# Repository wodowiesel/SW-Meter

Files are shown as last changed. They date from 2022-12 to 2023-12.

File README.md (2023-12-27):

# SW-Meter

Custom PCB design of an external S-&amp;Watt-Meter for radios. Useful for all radio enthusiasts and amateur HAM operators.

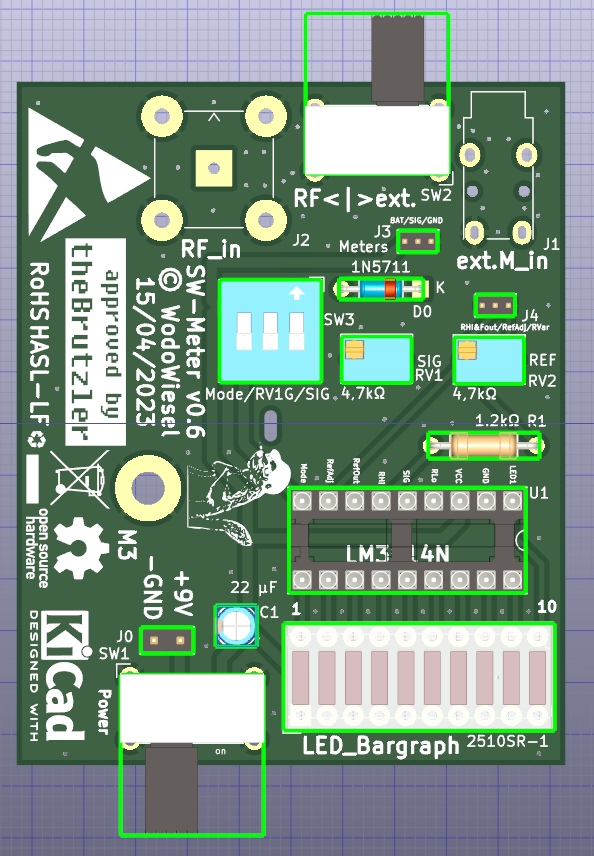
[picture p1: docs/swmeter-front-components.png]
PCB


## DISCLAIMERS

This is still "work-in-progress (WIP)" so I do NOT take any kind of warranty/responsibility for damages or data losses!

You can use this at your own risk without any guarantees and put device on non-conductive surface or enclosure!

If you like the new design you are free to share it!

Have fun and 73 :)

## HARDWARE

- 1x Custom THT PCB: (B) 66 x (L) 53 x (H) ~2 mm + ~15 mm parts height

  by WodoWiesel (wodowiesel@quantentunnel.de)

- 1x BNC male connector 50 Ohm Impedance

- 1x T-Adapter/cable for antenna/transceiver

- 1x 3.5 mm (or 2.5) audio jack female connector incl. a cable for hook up to your radio

- 1x +9 V Block Battery + 1x click connector

- 1x 330 Ohm Resistor – optional for LED

- 3x Variable Trimmer resistors 3-pins (1x1.2k & 2x4.7 kOhm)

- 1x Electrolytic Capacitor ~22 µF (pol.)

- 1x 3-pos. DIP-switch for additional signal/graph modes

- 1x On/Off-switch

- 1x 2-pos. 3-pin switch - for Input selection

- 2x DC-Volt-Meters 3-pins

- 1x Female Pin Headers/Socket - recommended for driver chip

- 1x LM3914 (linear), or 3915/16 (logarithmic dB) dot/bar display driver from Texas Instruments

  extra calculator (https://www.electro-tech-online.com/tools/LM3914V2.php)

- 1x 1N914 fast-switching Schottky Diode - to prevent backflow

- 10x LEDs (v0.5) or 1x Bar-Graph (v0.7)

- 1x M3 short flat head screw

- maybe metal case or 3D printed enclosure for isolation

- 1x Soldering iron & Screwdriver

- Solder + flux + IPA + brush + paper

- Multimeter/Oscilloscope for verification

## Credits

©️ 2022/23 WodoWiesel (https://github.com/wodowiesel/ & https://www.twitch.com/wodowiesel/)

The new design was checked by the electrical engineer theBrutzler

(https://github.com/theBrutzler/ & https://www.twitch.com/theBrutzler/)

The new optimized PCB was designed with free KiCAD software (https://www.kicad.org/)

The PCB should be produced at a manufacturer (like PCBWay) with the RoHS lead-free option for environmental protection

## LICENSE

This project is licensed under:

CERN Open Hardware License Version 2 - Weakly Reciprocal

Short identifier CERN-OHL-W-2.0

[LICENSE Source](https://spdx.org/licenses/CERN-OHL-W-2.0.html)

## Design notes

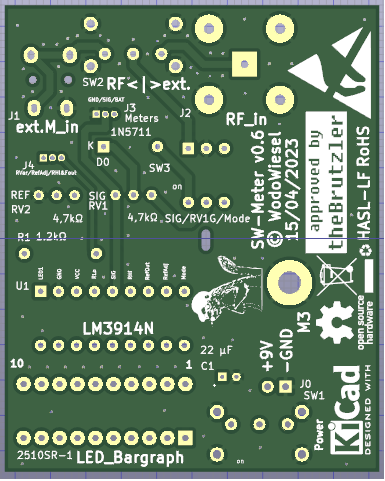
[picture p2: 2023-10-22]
docs/swmeter-back.png

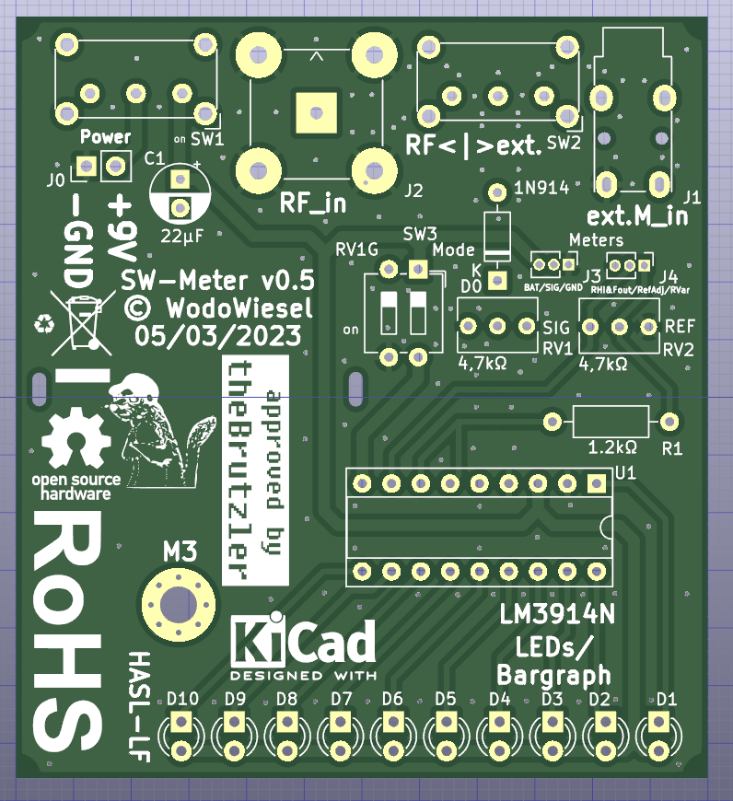
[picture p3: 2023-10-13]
docs/swmeter-front-led.png

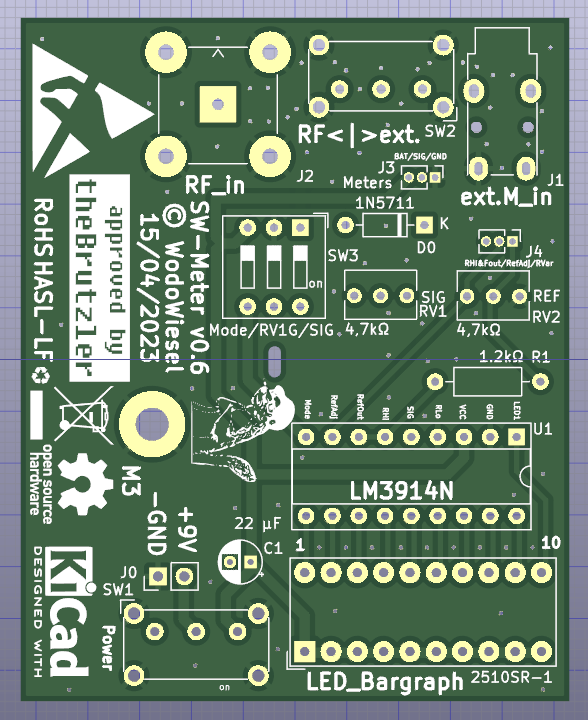
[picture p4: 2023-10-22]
docs/swmeter-front.png

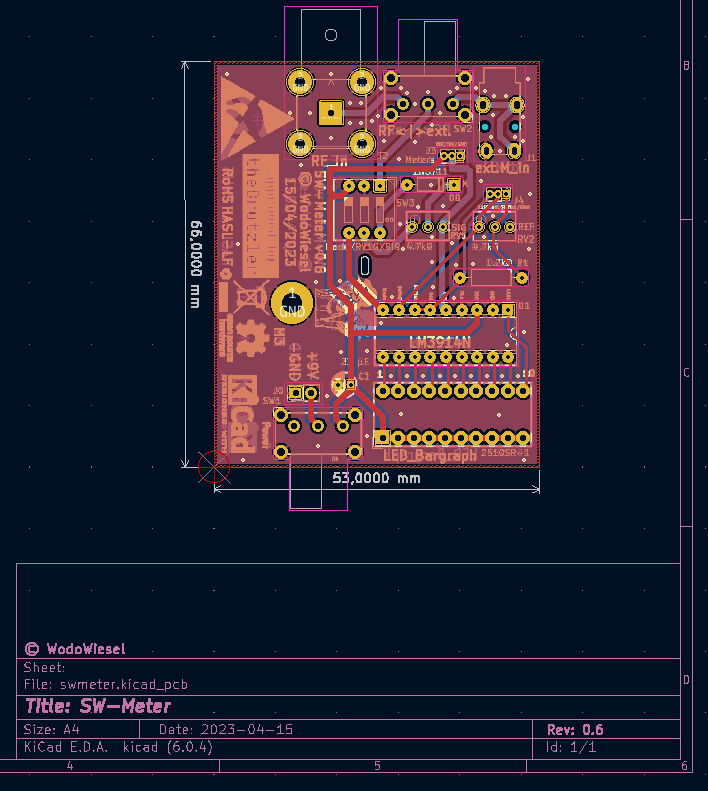
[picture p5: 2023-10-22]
docs/swmeter-v0.6-pcb.PNG

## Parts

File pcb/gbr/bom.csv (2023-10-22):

Designator | Footprint | Quantity | Value | LCSC Part #
BAR1 | HDSP-4836 | 1 | 2510SR-1
SW2 | SW_E-Switch_EG1224_SPDT_Angled | 1 | SW_SPDT
C1 | CP_Radial_D4.0mm_P2.00mm | 1 | 22 µF
J1 | Jack_3.5mm_Lumberg_1503_07_Horizontal | 1 | AudioPlug
RV1 | Potentiometer_Bourns_3266Y_Vertical | 1 | 4,7kΩ
SW1 | SW_E-Switch_EG1224_SPDT_Angled | 1 | SW_SPDT
J3 | PinHeader_1x03_P1.27mm_Vertical | 1 | Conn_01x03_Female
SW3 | SW_DIP_SPSTx03_Slide_9.78x9.8mm_W7.62mm_P2.54mm | 1 | SW_DIP_x03
D0 | D_DO-35_SOD27_P7.62mm_Horizontal | 1 | 1N5711
J4 | PinHeader_1x03_P1.27mm_Vertical | 1 | Conn_01x03_Female
R1 | R_Axial_DIN0207_L6.3mm_D2.5mm_P10.16mm_Horizontal | 1 | 1.2kΩ
U1 | DIP-18_W7.62mm_Socket | 1 | LM3914N
J2 | BNC_TEConnectivity_1478035_Horizontal | 1 | Conn_Coaxial
J0 | PinHeader_1x02_P2.54mm_Vertical | 1 | Conn_01x02_Female
RV2 | Potentiometer_Bourns_3266Y_Vertical | 1 | 4,7kΩ

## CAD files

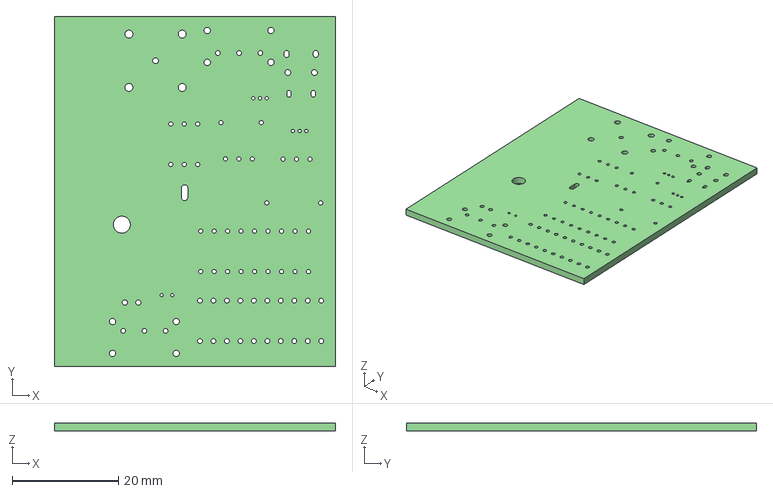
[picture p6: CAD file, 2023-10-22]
pcb/export/swmeter.step
53.0 x 66.0 x 1.60 mm

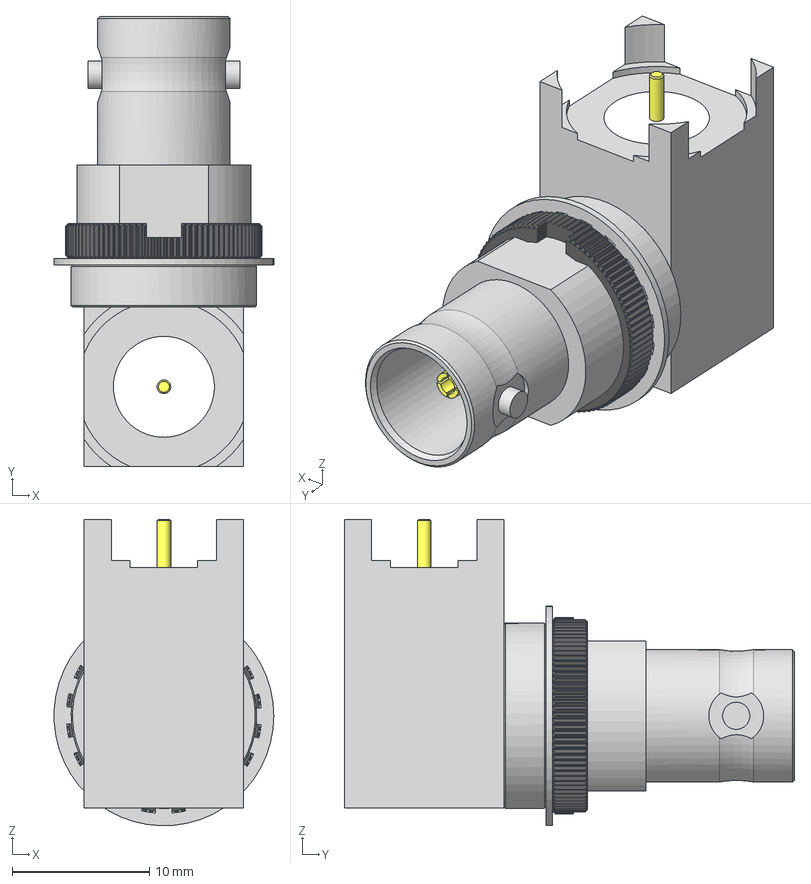
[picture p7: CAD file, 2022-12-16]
pcb/shapes3D/BNC7T-J-P-HN-RA-BH1.stp
16.0 x 32.8 x 22.3 mm
BNC7T-G-P-HN-RA-BH1_n
BNC7T-G-P-HN-RA-BH1_w
BNC7T-G-P-HN-RA-BH1_p
BNC7T-G-P-HN-RA-BH1_i
BNC7T-G-P-HN-RA-BH1_s

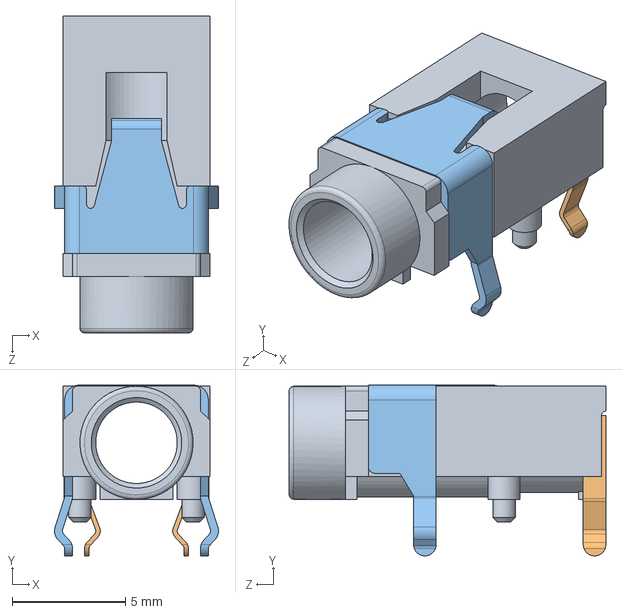
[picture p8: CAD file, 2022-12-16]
pcb/shapes3D/Lumberg_1503_07.stp
7.25 x 7.55 x 14.0 mm

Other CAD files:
pcb/swmeter.step

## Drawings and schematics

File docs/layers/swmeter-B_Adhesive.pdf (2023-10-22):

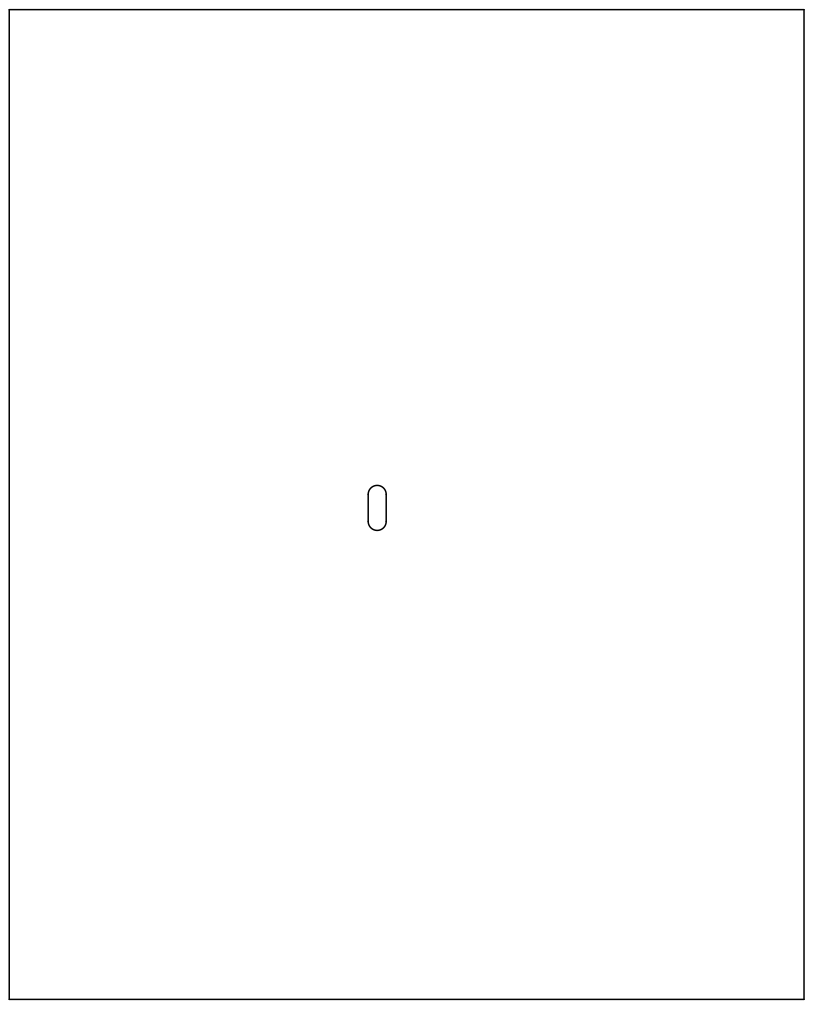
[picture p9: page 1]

File: swmeter.kicad_pcb Sheet: þÿ© WodoWiesel

Id: 1/1 Title: SW-Meter

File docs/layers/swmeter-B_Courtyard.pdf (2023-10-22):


File: swmeter.kicad_pcb Sheet: þÿ© WodoWiesel

Id: 1/1 Title: SW-Meter

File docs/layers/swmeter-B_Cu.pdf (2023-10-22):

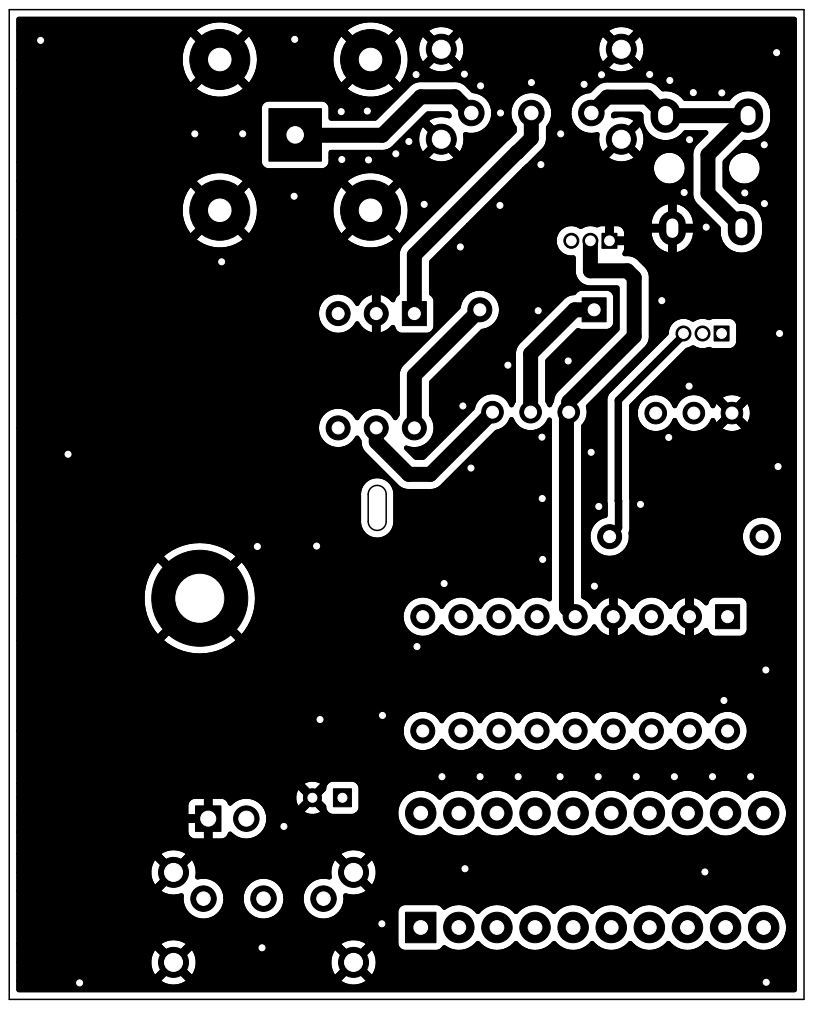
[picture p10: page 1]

File: swmeter.kicad_pcb Sheet: þÿ© WodoWiesel

Id: 1/1 Title: SW-Meter

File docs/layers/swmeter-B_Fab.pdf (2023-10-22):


File: swmeter.kicad_pcb Sheet: þÿ© WodoWiesel

Id: 1/1 Title: SW-Meter

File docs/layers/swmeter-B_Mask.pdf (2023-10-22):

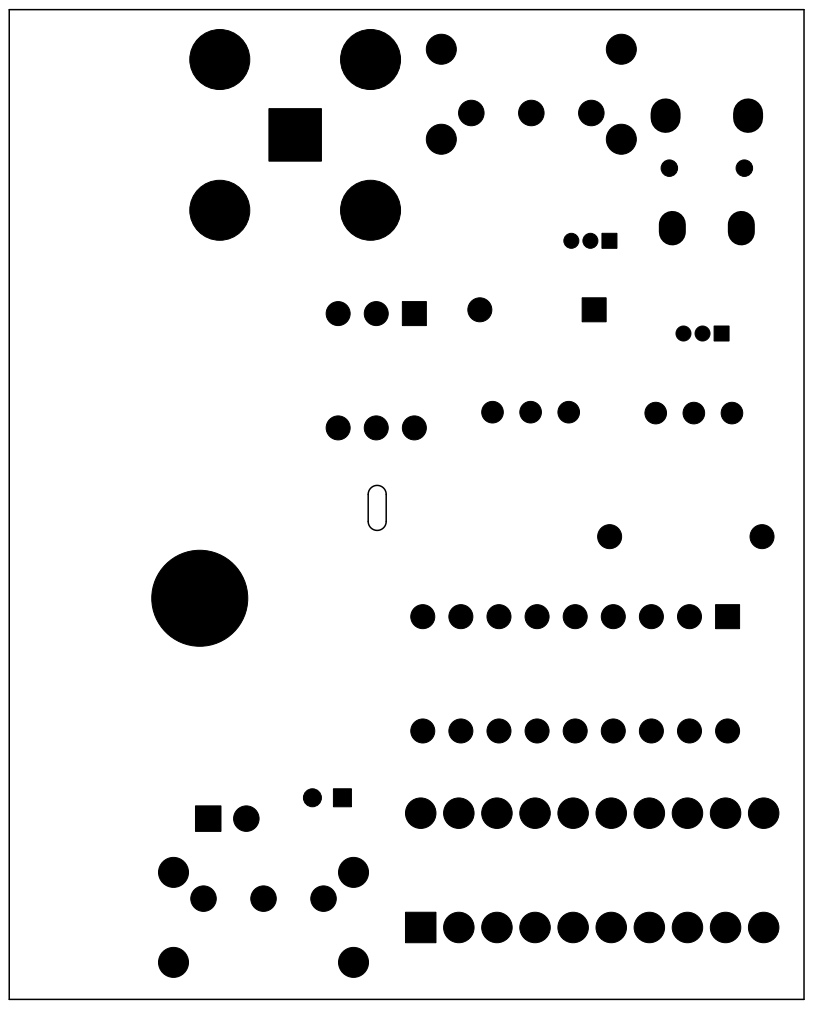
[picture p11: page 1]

File: swmeter.kicad_pcb Sheet: þÿ© WodoWiesel

Id: 1/1 Title: SW-Meter

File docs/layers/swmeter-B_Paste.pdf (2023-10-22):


File: swmeter.kicad_pcb Sheet: þÿ© WodoWiesel

Id: 1/1 Title: SW-Meter

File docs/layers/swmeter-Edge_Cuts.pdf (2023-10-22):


File: swmeter.kicad_pcb Sheet: þÿ© WodoWiesel

Id: 1/1 Title: SW-Meter

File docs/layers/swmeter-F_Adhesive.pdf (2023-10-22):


File: swmeter.kicad_pcb Sheet: þÿ© WodoWiesel

Id: 1/1 Title: SW-Meter

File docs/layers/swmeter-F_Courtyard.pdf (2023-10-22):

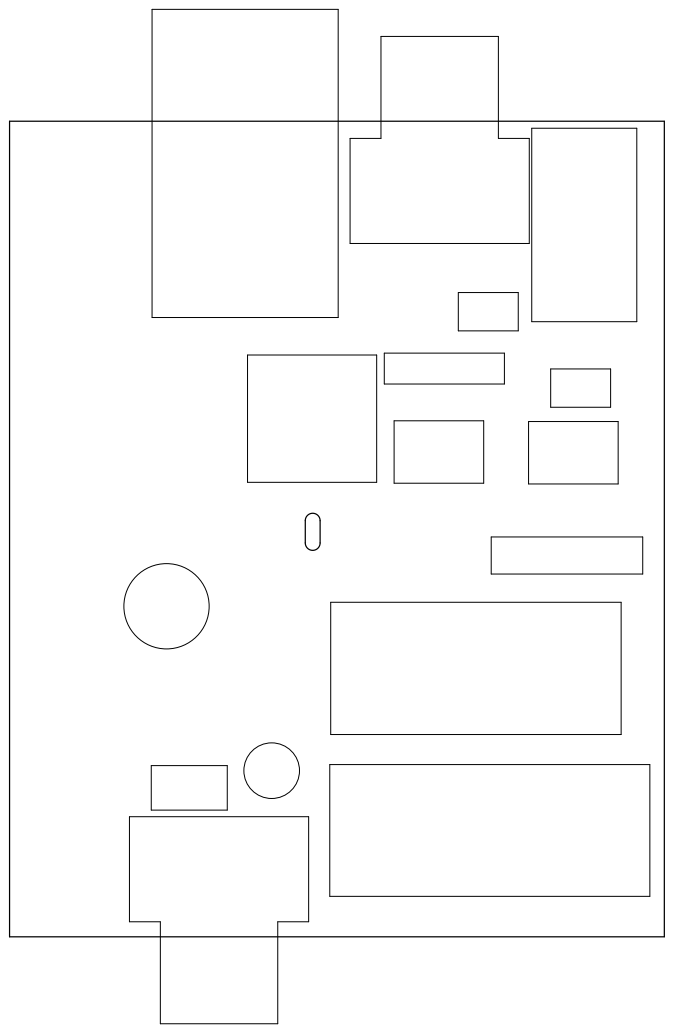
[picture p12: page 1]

File: swmeter.kicad_pcb Sheet: þÿ© WodoWiesel

Id: 1/1 Title: SW-Meter

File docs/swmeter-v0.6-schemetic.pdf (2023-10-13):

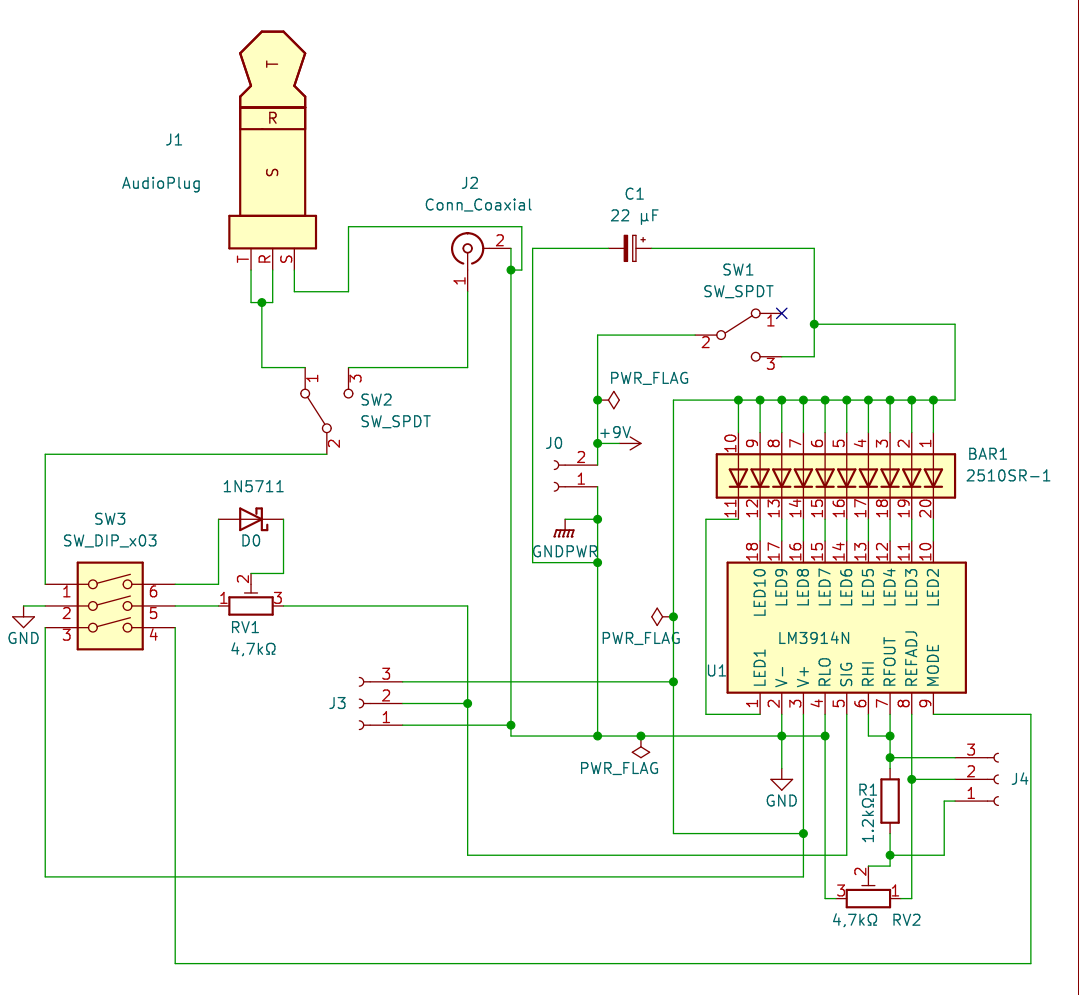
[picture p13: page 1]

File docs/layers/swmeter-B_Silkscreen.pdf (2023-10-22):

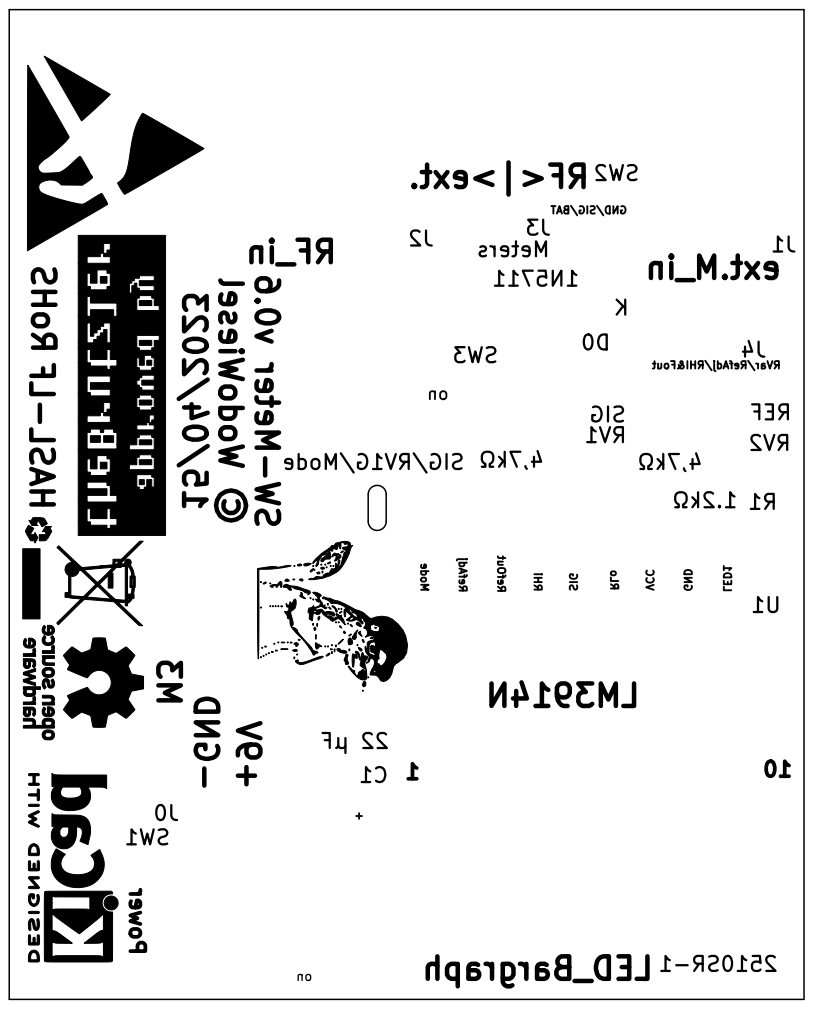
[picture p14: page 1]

Id: 1/1 Title: SW-Meter

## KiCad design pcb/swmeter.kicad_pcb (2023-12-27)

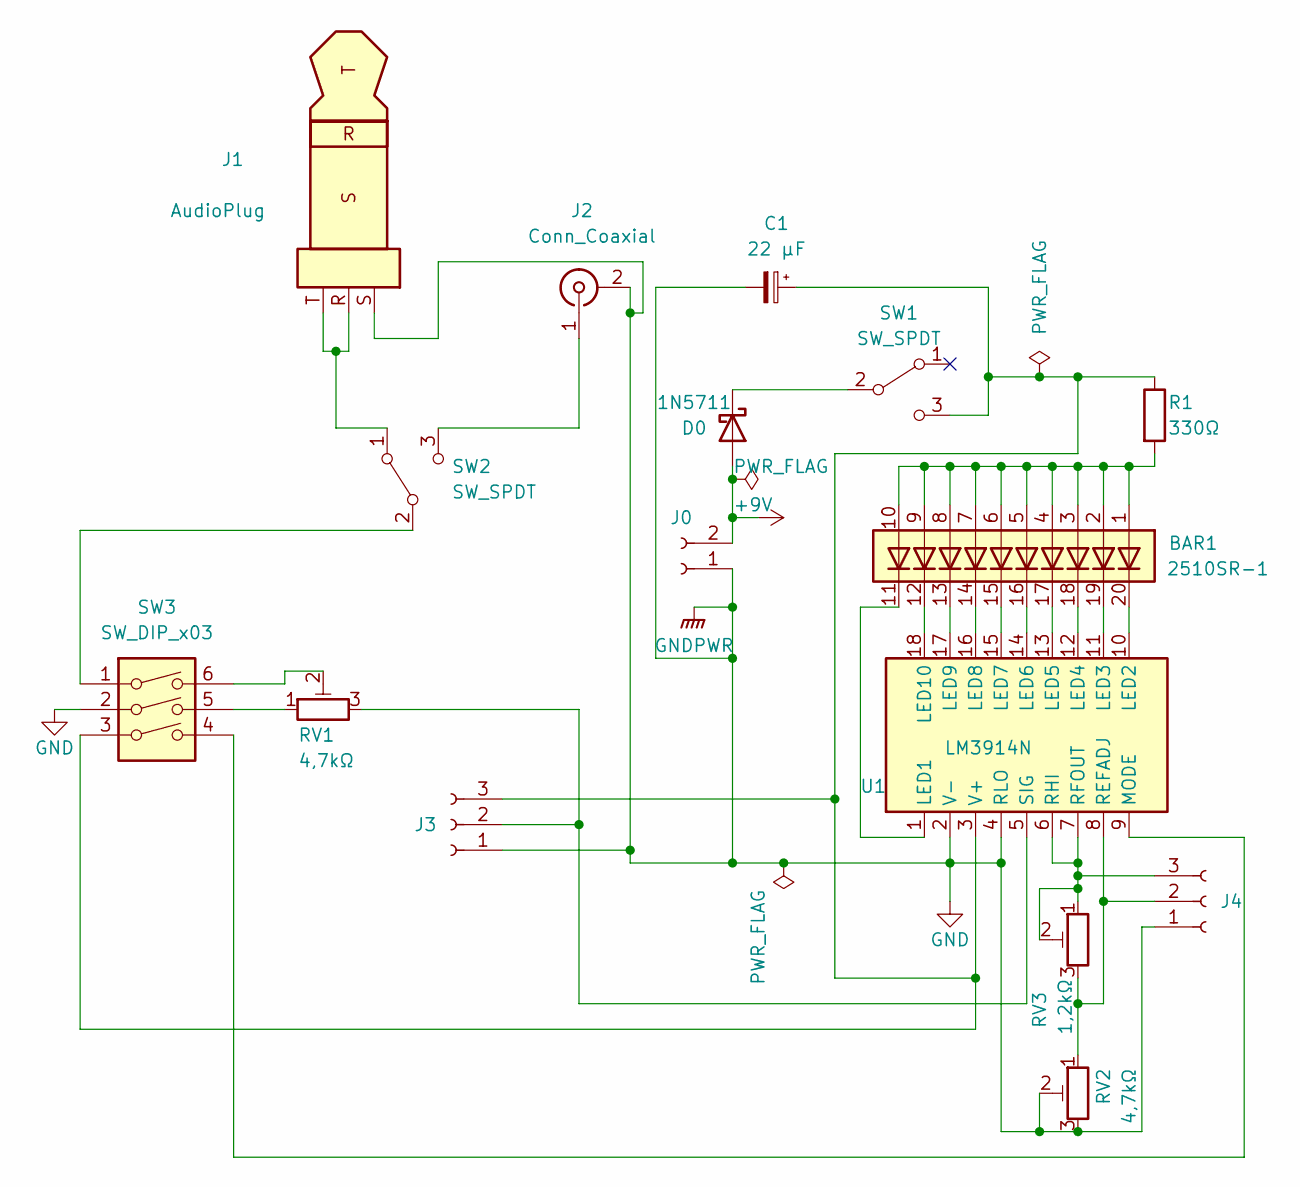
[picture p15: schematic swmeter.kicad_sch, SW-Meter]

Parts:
BAR1: 2510SR-1; HDSP-4836
C1: 22 µF; CP_Radial_D4.0mm_P2.00mm
D0: 1N5711; D_DO-35_SOD27_P7.62mm_Horizontal
J0: Conn_01x02_Female; PinHeader_1x02_P2.54mm_Vertical
J1: AudioPlug; Jack_3.5mm_Lumberg_1503_07_Horizontal
J2: Conn_Coaxial; BNC_TEConnectivity_1478035_Horizontal
J3, J4: Conn_01x03_Female; PinHeader_1x03_P2.54mm_Vertical
R1: 330Ω; R_Axial_DIN0207_L6.3mm_D2.5mm_P7.62mm_Horizontal
RV1, RV2: 4,7kΩ; Potentiometer_Bourns_3266Y_Vertical
RV3: 1,2kΩ; Potentiometer_Bourns_3266Y_Vertical
SW1: SW_SPDT; SW_Slide_1P2T_CK_OS102011MS2Q
SW2: SW_SPDT; SW_E-Switch_EG1224_SPDT_Angled
SW3: SW_DIP_x03; SW_DIP_SPSTx03_Slide_9.78x9.8mm_W7.62mm_P2.54mm
U1: LM3914N; DIP-18_W7.62mm_Socket

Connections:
+9V: D0.2 (A), J0.2
GND: C1.2, J0.1, J1.S, J2.2 (Ext), J3.1, J4.1, RV2.2, RV2.3, SW3.2, U1.2 (V-), U1.4 (RLO); also elsewhere on the board
unnamed: BAR1.1 (A), BAR1.2 (A), BAR1.3 (A), BAR1.4 (A), BAR1.5 (A), BAR1.6 (A), BAR1.7 (A), BAR1.8 (A), BAR1.9 (A), BAR1.10 (A), R1.2
unnamed: BAR1.11 (K), U1.1 (LED1)
unnamed: BAR1.12 (K), U1.18 (LED10)
unnamed: BAR1.13 (K), U1.17 (LED9)
unnamed: BAR1.14 (K), U1.16 (LED8)
unnamed: BAR1.15 (K), U1.15 (LED7)
unnamed: BAR1.16 (K), U1.14 (LED6)
unnamed: BAR1.17 (K), U1.13 (LED5)
unnamed: BAR1.18 (K), U1.12 (LED4)
unnamed: BAR1.19 (K), U1.11 (LED3)
unnamed: BAR1.20 (K), U1.10 (LED2)
unnamed: C1.1, J3.3, R1.1, SW1.3 (C), SW3.3, U1.3 (V+)
unnamed: D0.1 (K), SW1.2 (B)
unnamed: J1.R, J1.T, SW2.1 (A)
unnamed: J2.1 (In), SW2.3 (C)
unnamed: J3.2, RV1.3, U1.5 (SIG)
unnamed: J4.2, RV2.1, RV3.3, U1.8 (REFADJ)
unnamed: J4.3, RV3.1, RV3.2, U1.6 (RHI), U1.7 (RFOUT)
unnamed: RV1.1, SW3.5
unnamed: RV1.2, SW3.6
unnamed: SW2.2 (B), SW3.1
unnamed: SW3.4, U1.9 (MODE)

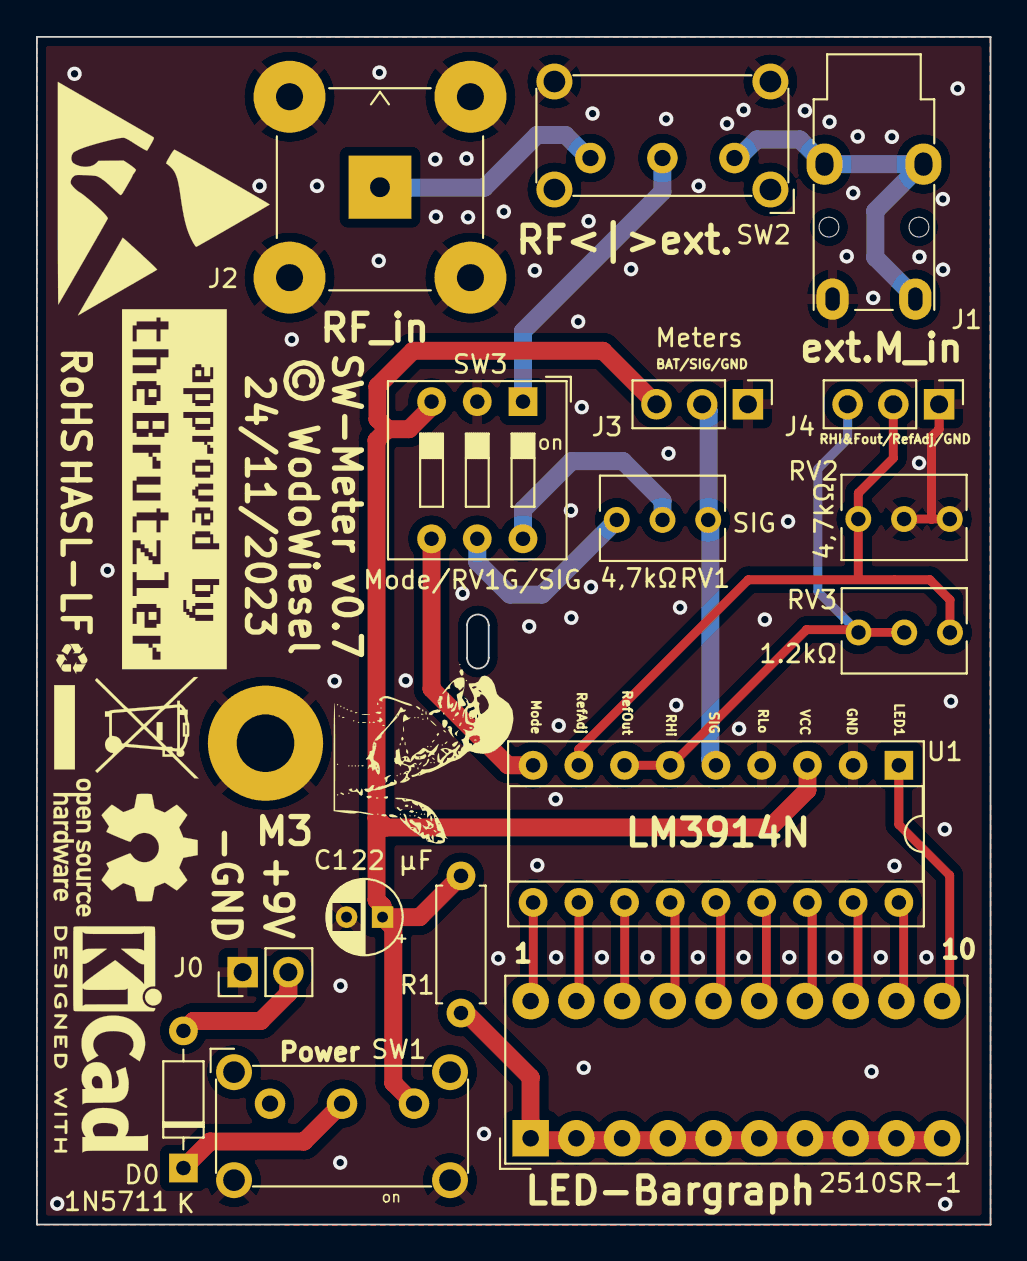
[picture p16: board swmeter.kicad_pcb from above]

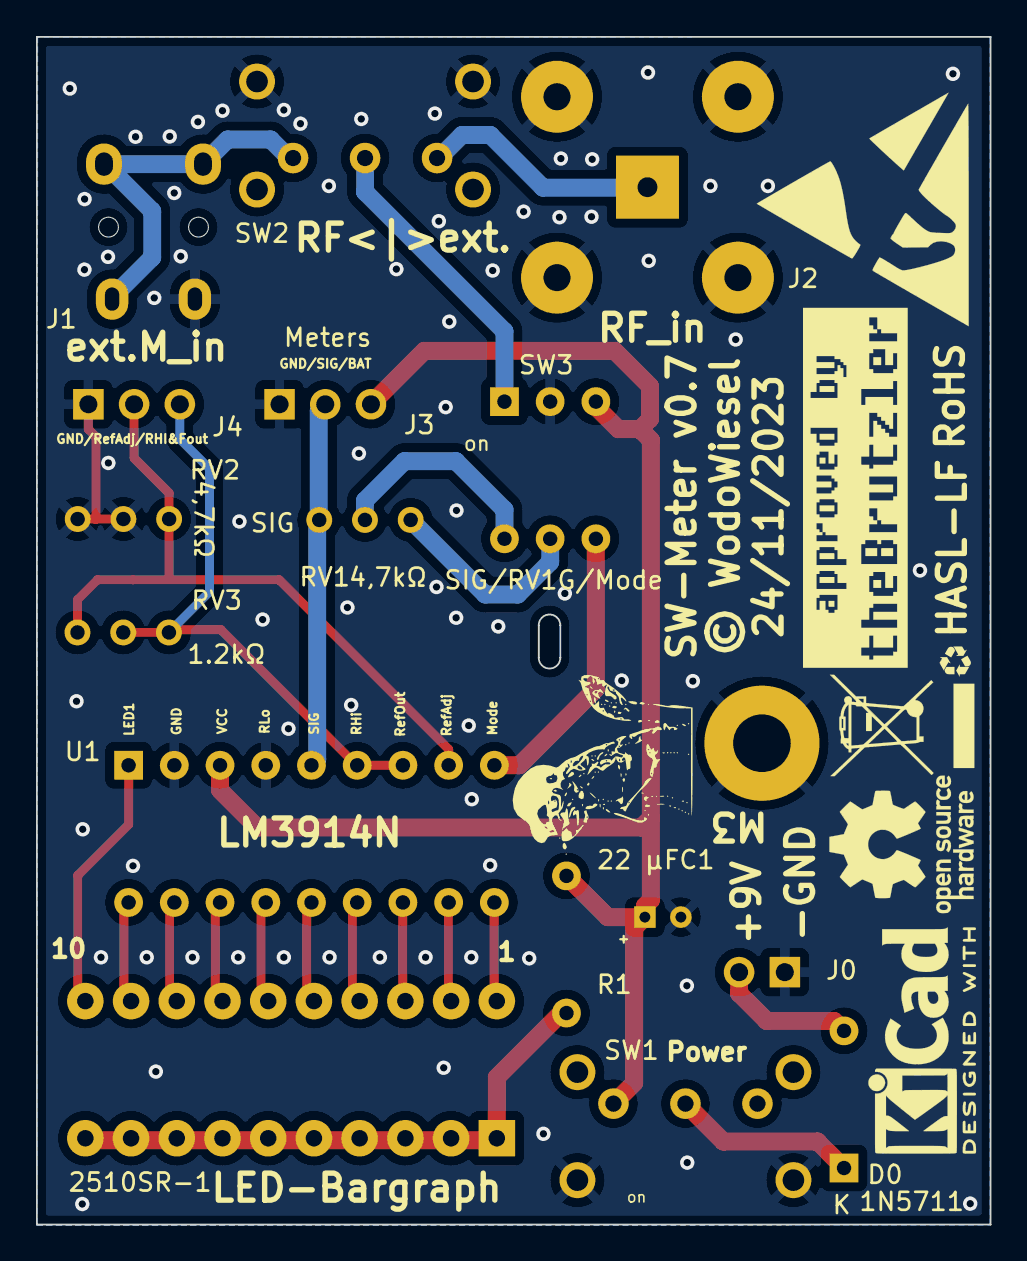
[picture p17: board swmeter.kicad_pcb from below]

Board: 2 copper layers, 53.0 x 66.0 mm, 31 parts (7 on the bottom side), 24 nets.

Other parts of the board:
G1, G11: LOGO; approved_theBrutzler
G2, G22: LOGO; wiesel-kicad-back-white
G9, G99: LOGO; recycling-symbol-kicad
REF0, REF00: WEEE-Logo_5.6x8mm_SilkScreen
REF3, REF33: OSHW-Logo_7.5x8mm_SilkScreen
REF7**, REF77**: ESD-Logo_13.2x12mm_SilkScreen
REF8**, REF88**: KiCad-Logo2_5mm_SilkScreen
REF99**: MountingHole_3.2mm_M3_Pad

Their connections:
GND: REF99**.1; also elsewhere on the board

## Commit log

2022-10-08 initial upload PCB design
    initial upload PCB design
    [swmeter-B_Cu.gbr, swmeter-B_Mask.gbr, swmeter-B_Paste.gbr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]
2022-10-12 design optimizations by adding input switch
    [swmeter-B_Cu.gbr, swmeter-B_Mask.gbr, swmeter-B_Paste.gbr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]
2022-10-21 Opimizations - prettify Silkscreens & Routings - DC-Meter 3-Pin Hheader - Gerber & Layer Files
    [smeter.dsn, smeter.step, swmeter-B_Adhesive.dxf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]
2022-10-28 clean up folders
    [smeter.dsn, smeter.step, swmeter.dsn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]
2022-11-07 schematics update
2022-11-07 export update
    [smeter.dsn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]
2022-11-15 -double trace width -use 2 same switches -add recycling logo -add HASL info -optimize gnd-plane
    [smeter.dsn, swmeter-B_Courtyard.dxf, swmeter-B_Cu.dxf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]
2022-12-17 make pretty
    [swmeter-B_Adhesive.gbr, swmeter-B_Courtyard.gbr, swmeter-B_Cu.gbr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]
2023-03-04 improve readability
    improve readability
    [swmeter-B_Adhesive.gbr, swmeter-B_Courtyard.gbr, swmeter-B_Cu.gbr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]
2023-10-13 -update to compact bargraph design -add capacitor for battery
    [BNC7T-J-P-HN-RA-BH1.stp, Lumberg_1503_07.stp, designators.csv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]
2023-10-13 update 3d pcb png
2023-10-22 -mounting with gnd -removed orientation crosses
    [swmeter.kicad_pcb]
2023-10-22 update docs with new pcb layout
2023-10-22 -export layers -export gerber
    [bom.csv, designators.csv, positions.csv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]
2023-12-27 optimized trimmer schematics
    optimized trimmer schematics
    [swmeter.kicad_pcb, swmeter.kicad_sch]
2023-12-27 add diode for reverse polarity protection
    [swmeter.kicad_pcb, swmeter.kicad_sch]

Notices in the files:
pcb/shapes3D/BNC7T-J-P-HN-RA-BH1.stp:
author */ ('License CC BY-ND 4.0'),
